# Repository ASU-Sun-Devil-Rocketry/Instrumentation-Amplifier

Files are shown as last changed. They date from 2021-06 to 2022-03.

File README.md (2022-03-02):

<h1>Rail to Rail Instrumentation Amplifier with Regulated Supply</h1>

<p><u>Current PCB Revision:</u> 2.0 <p>
<p>PCB Part Number: L0001</p>
<p>Design Folder: <a href="https://drive.google.com/drive/folders/1LhDJDFwJdzdXdzs4db-Y9qnFIhuEQvka">Click Here</a></p>

<p>The instrumentation amplifier IC uses an adjustable gain differential amplifier with buffered inputs to amplify the readings from an analog sensor using a wheatstone bridge such as a load cell or pressure transducer. The amplifier supply voltage was chosen to match that of the pressure transducers it is intended to be used with.</p>

<b>Working Directory Structure:</b>

<p>
   doc: documentation
   
   src: source design files, e.g. schematic and board files

   lib: libraries for schematic symbols and footprints

   production: files needed for pcb fabrication, e.g. gerbers, profile, drill file

   sim: simulation files 

   cad: 3d models
  
   img: images of circuit/footprints for github display 
</p>

<h2>Schematic:</h2>

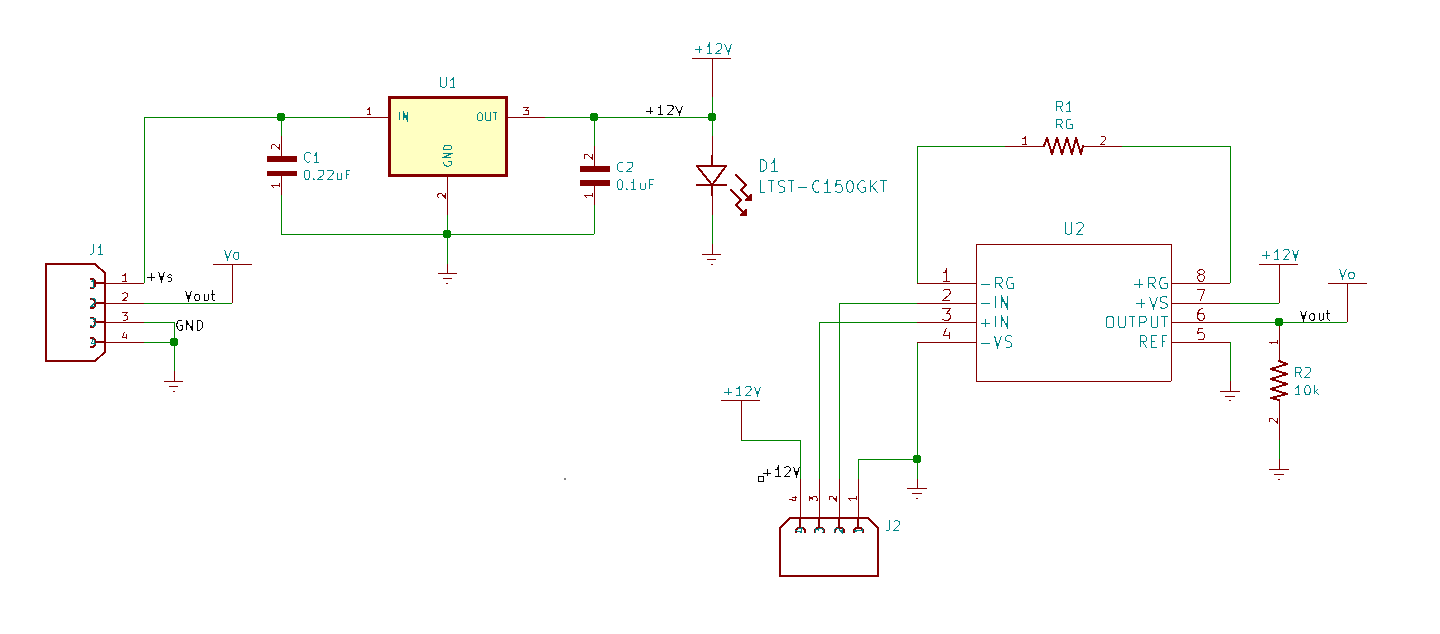
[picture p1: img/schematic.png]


<h2>PCB Layout: </h2>
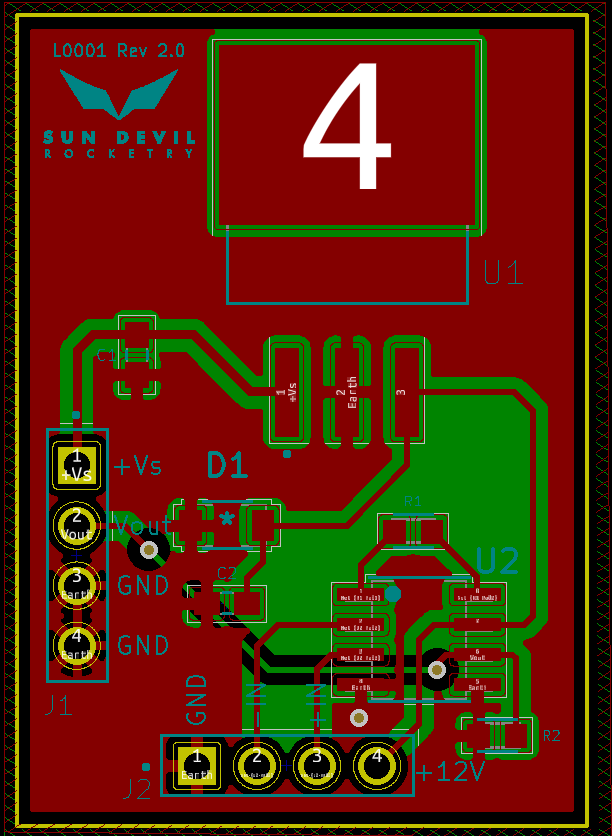
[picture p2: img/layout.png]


<h2>Gerber Veiws:</h2>
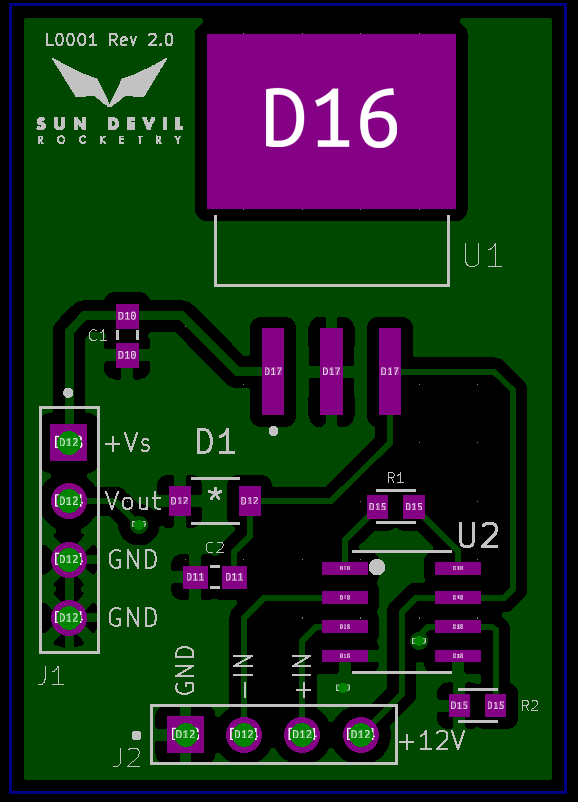
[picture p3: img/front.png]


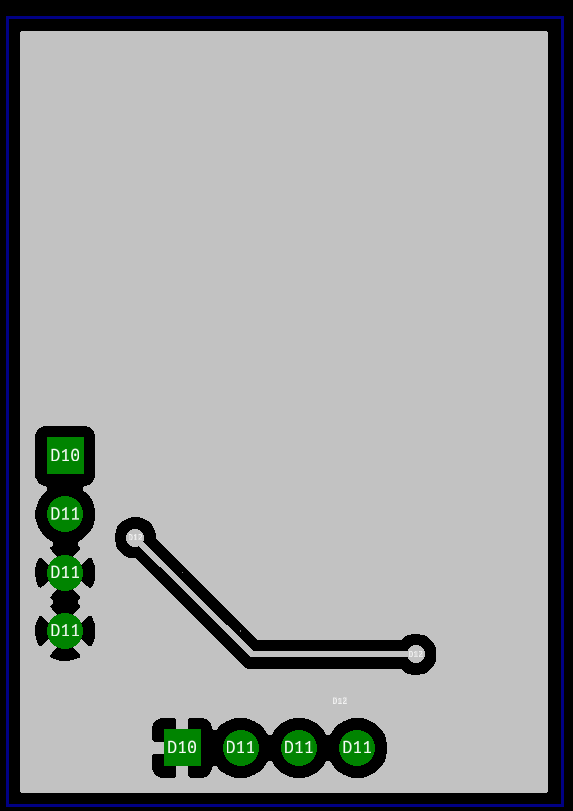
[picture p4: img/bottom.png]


<h2> 3D Model: </h2>

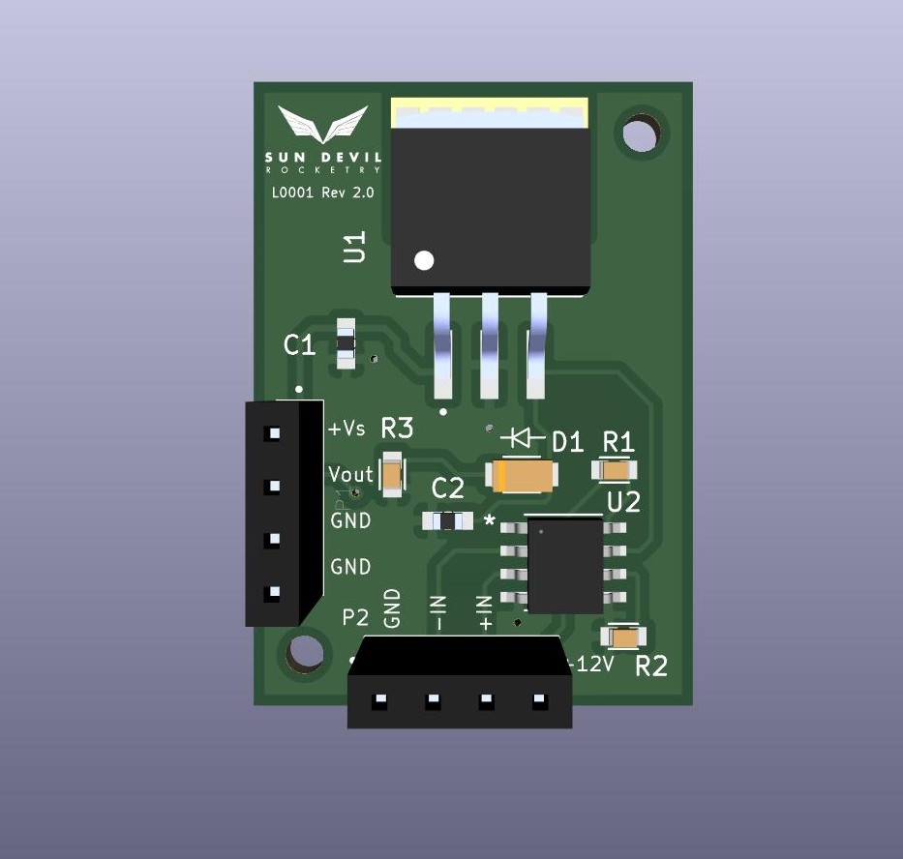
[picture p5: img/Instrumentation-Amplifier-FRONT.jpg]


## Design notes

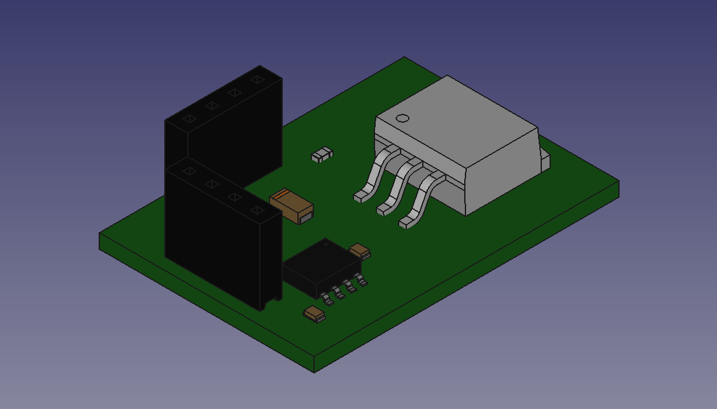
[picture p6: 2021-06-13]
img/3Dview.png

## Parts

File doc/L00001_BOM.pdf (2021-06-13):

# L0001 Instrumentation Amplifier BOM

Project: | Liquids Engine
Revision: | 2.0
Date: | 6/12/2021
Author: | Colton Acosta
Qty | Component | Manufacturer | Part Number | Designator | Do Not Populate | Price per Unit | Data Sheet | Source | Part in Stock | Alternate Parts
1 | Positive 12V linear regulator | Texas Instruments | LM7812S/NOPB | U1 | | $2.07 | AD623ARZ-R7 (https://drive.google.com/file/d/1YfVe5k8k3W6Ymcjjqmwe3NW82-qWHDOC/view?usp=sharing) | Digikey (https://www.digikey.com/en/products/detail/texas-instruments/LM7812S-NOPB/6110586) | No
1 | Rail to rail instrumentation amplifier | Analog Devices Inc. | AD623ARZ-R7 | U2 | | $5.53 | AD623ARZ-R7 (https://drive.google.com/file/d/1YfVe5k8k3W6Ymcjjqmwe3NW82-qWHDOC/view?usp=sharing) | Digikey (https://www.digikey.com/en/products/detail/analog-devices-inc/AD623ARZ-R7/652817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) | No
2 | 4 Pin connector female socket | Sullins Connector Solutions | PPTC041LFBN-RC | J1,J2 | | $0.45 | PPTC041LFBN-RC (https://drive.google.com/file/d/1xhb6gxP4Ug4C7Le1FVLg7WC_u6vesKIo/view?usp=sharing) | Digikey (https://www.digikey.com/en/products/detail/sullins-connector-solutions/PPTC041LFBN-RC/810144) | No
1 | 0.22 uF 0603 ceramic capacitor | Yageo | CC0603JRX7R8BB224 | C1 | | $0.22 | CC0603JRX7R8BB224 (https://drive.google.com/file/d/1omFNLfhEc18LIa5NOgsOFH_oAnptoYJs/view?usp=sharing) | Digikey (https://www.digikey.com/en/products/detail/yageo/CC0603JRX7R8BB224/5883662) | Yes
1 | 0.1 uF 0603 ceramic capacitor | KEMET | C0603C104J4RACTU | C2 | | $0.14 | C0603C104J4RACTU (https://drive.google.com/file/d/1a8FNZlWlnpfUzrwQWmMULMp5qRUnLx6e/view?usp=sharing) | Digikey (https://www.digikey.com/en/products/detail/kemet/C0603C104J4RACTU/411096) | Yes
1 | Green LED | Lite-On Inc | LTST-C150GKT | D1 | | $0.31 | LTST-C150GKT (https://drive.google.com/file/d/1ds0Y3mfrIqkNiykMavCPhlnYWgMl9Ngj/view?usp=sharing) | Digikey (https://www.digikey.com/en/products/detail/lite-on-inc/LTST-C150GKT/269216) | No
1 | 10kOhm 0603 resistor | Vishay | MCT0603MD1002BP100 | R2 | | $0.72 | MCT0603MD1002BP100 (https://drive.google.com/file/d/1nYTzGDgxme7YbRyGwEk438HFMVYf_WEx/view?usp=sharing) | Digikey (https://www.digikey.com/en/products/detail/vishay-beyschlag-draloric-bc-components/MCT0603MD1002BP100/2092113) | Yes
1 | 2kOhm 0603 resistor | Stackpole Electronics Inc | RNCP0603FTD2K00 | R1 | | $0.10 | RNCP0603FTD2K00 (https://drive.google.com/file/d/1EkjHNJRvKX0j5lXw98EbTa6WFv9tNLef/view?usp=sharing) | Digikey (https://www.digikey.com/en/products/detail/stackpole-electronics-inc/RNCP0603FTD2K00/2240114) | Yes

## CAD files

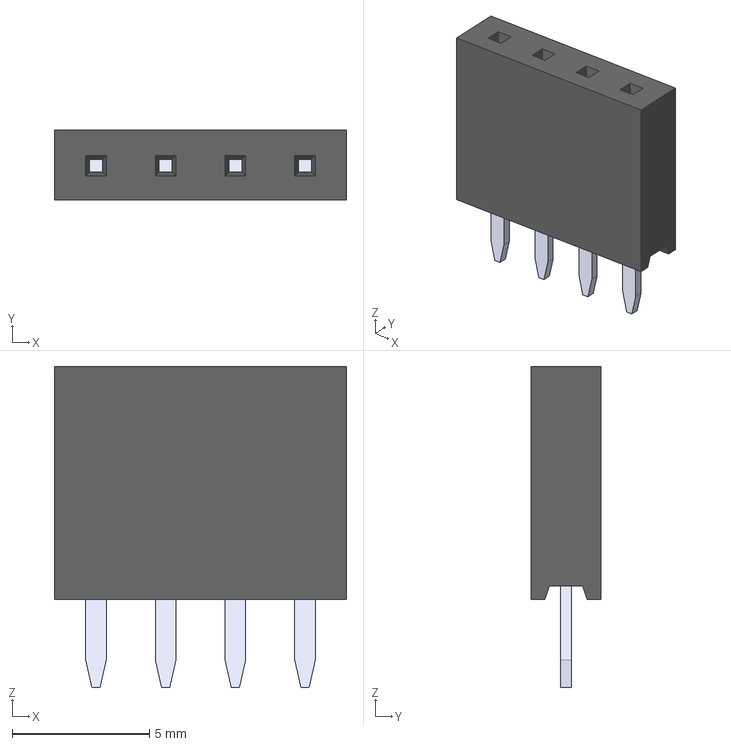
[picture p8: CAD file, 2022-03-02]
CAD/3Dfiles/Sullins_-_PPTC041LFBN-RC.step
10.7 x 2.54 x 11.7 mm

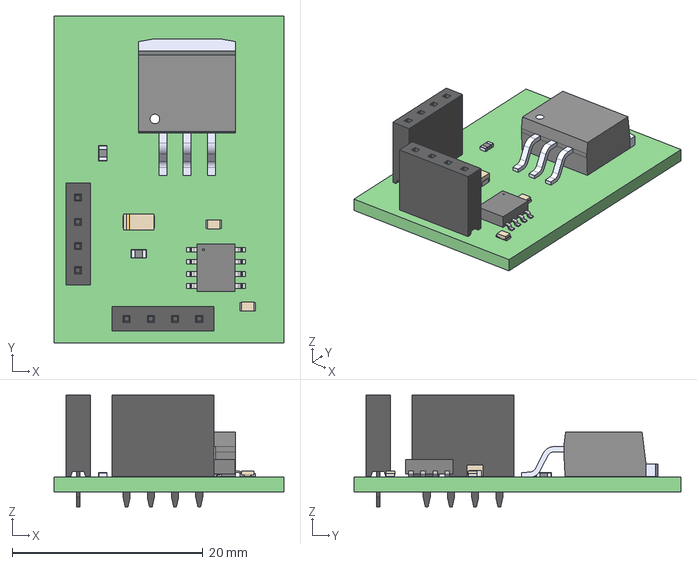
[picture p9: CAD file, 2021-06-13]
CAD/Instrumentation-Amplifier.step
24.1 x 34.3 x 11.7 mm

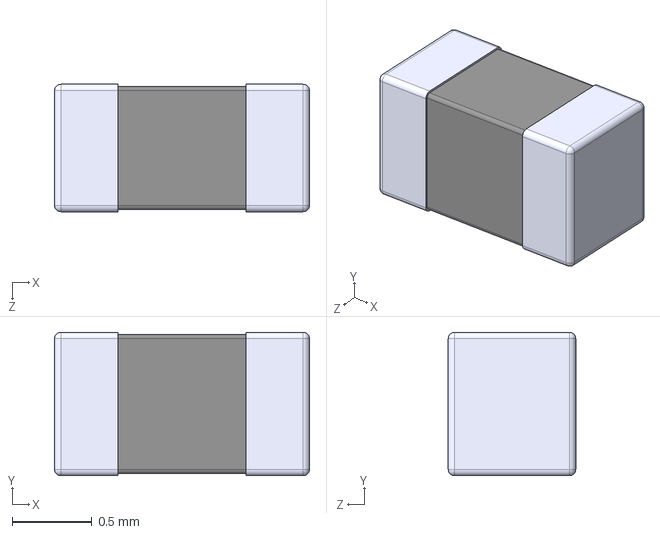
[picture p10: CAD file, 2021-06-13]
CAD/3Dfiles/CC0603JRX7R8BB224.STEP
1.60 x 0.9 x 0.8 mm

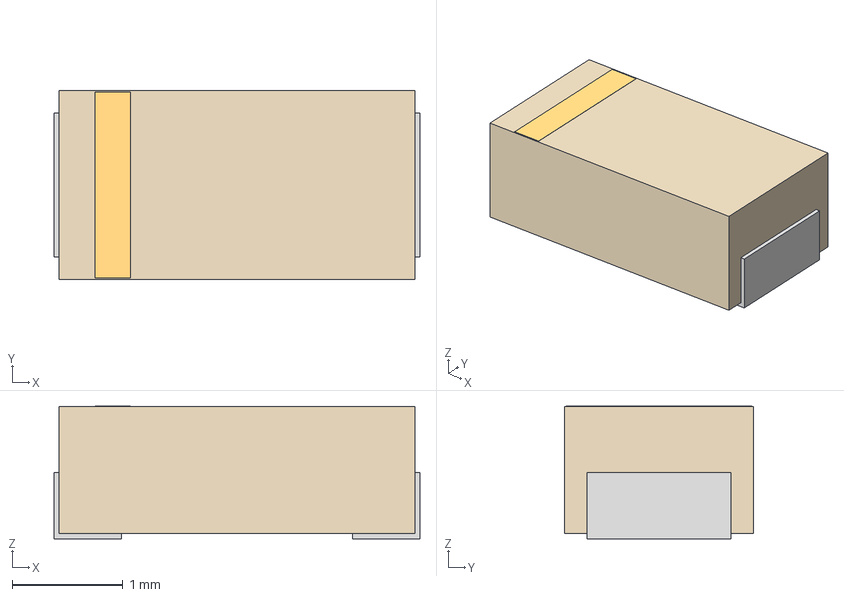
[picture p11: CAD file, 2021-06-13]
CAD/3Dfiles/LED_LTST-C150GKT_LTO.step
3.30 x 1.70 x 1.20 mm

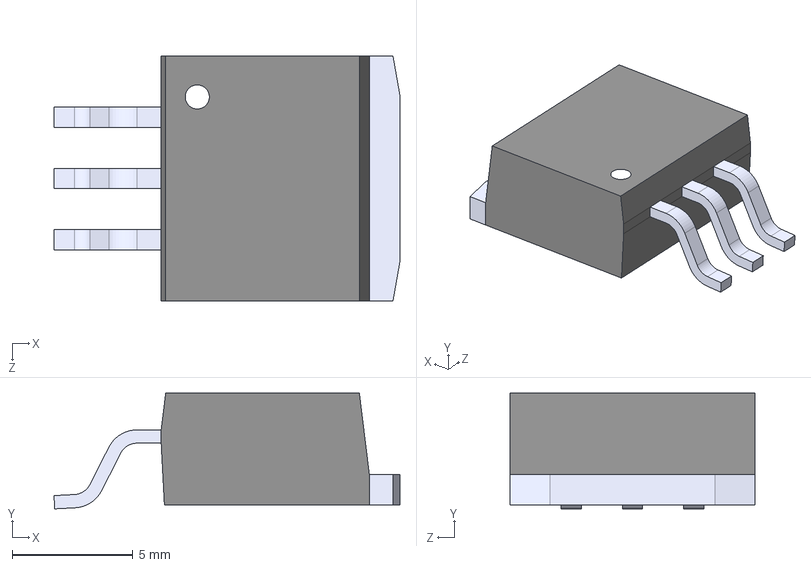
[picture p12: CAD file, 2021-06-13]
CAD/3Dfiles/NOPB.STEP
14.4 x 4.80 x 10.2 mm

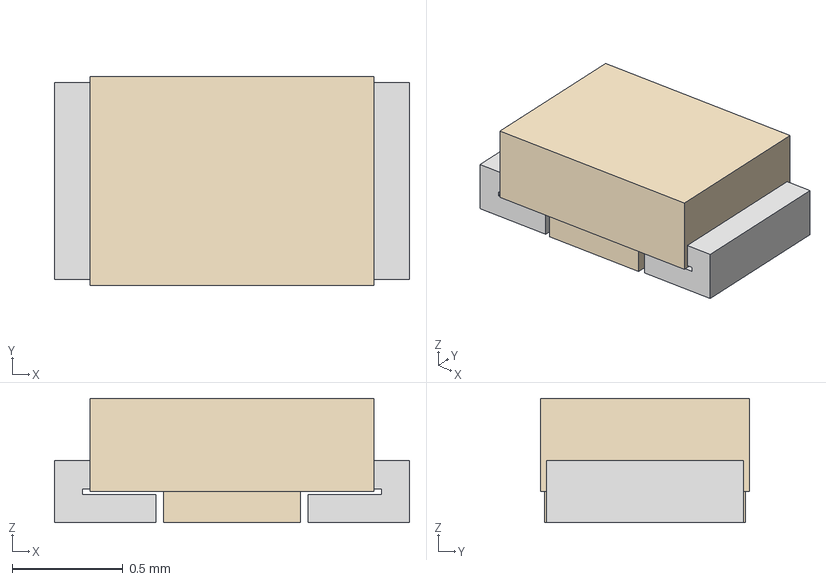
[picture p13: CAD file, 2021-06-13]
CAD/3Dfiles/RES_MCT_0603_VIS.step
1.60 x 0.94 x 0.559 mm

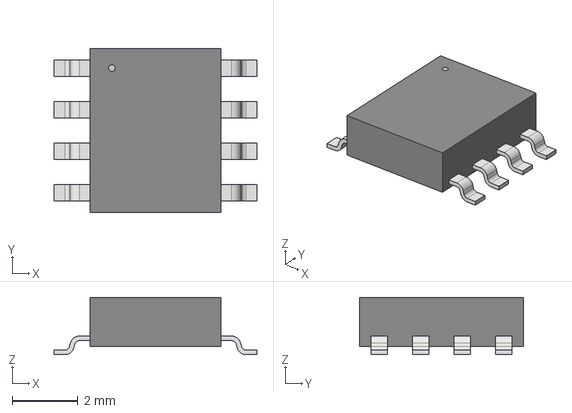
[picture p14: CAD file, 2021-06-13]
CAD/3Dfiles/R_8_ADI.step
6.20 x 5.00 x 1.75 mm

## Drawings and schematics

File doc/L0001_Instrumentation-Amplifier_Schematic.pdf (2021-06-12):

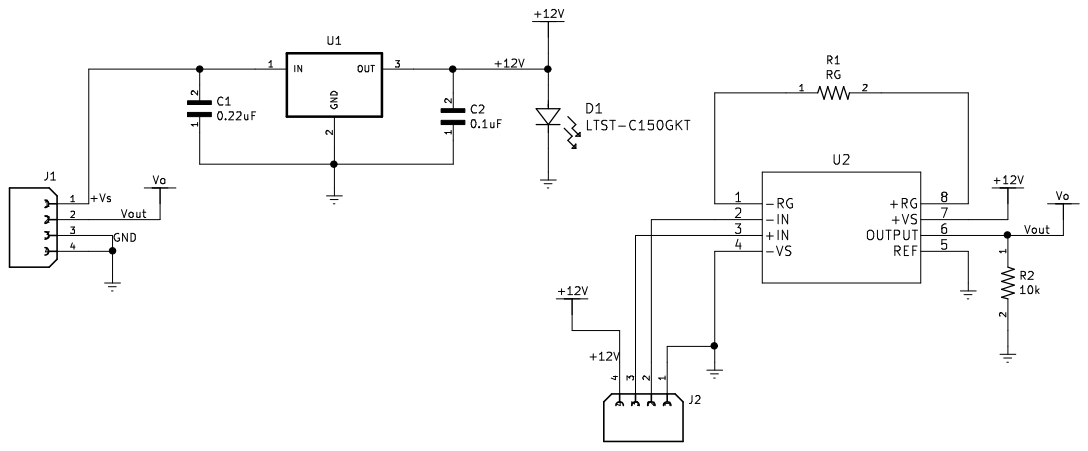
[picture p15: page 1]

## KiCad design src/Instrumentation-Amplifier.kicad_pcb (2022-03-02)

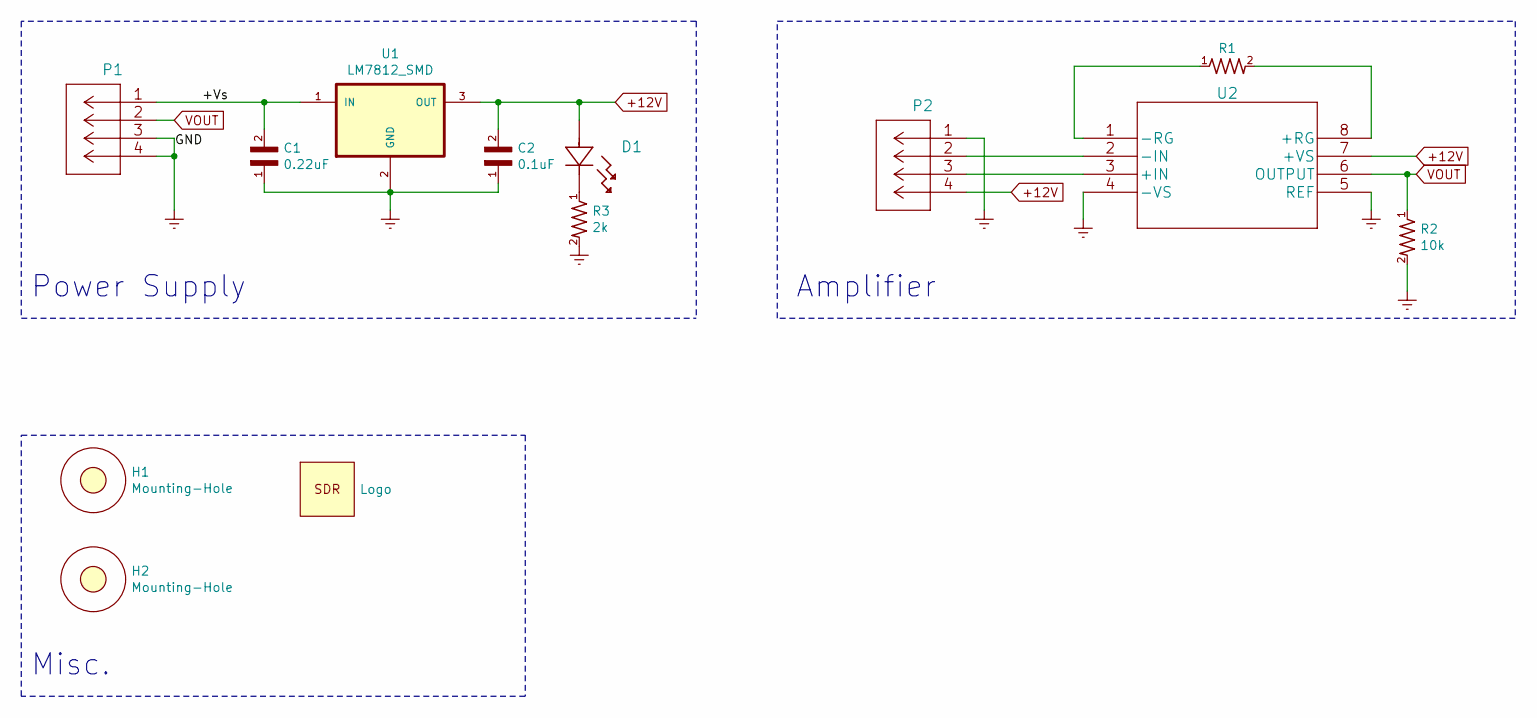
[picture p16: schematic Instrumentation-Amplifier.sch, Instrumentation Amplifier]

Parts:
C1: 0.22uF; CAP_0603
C2: 0.1uF; CAP_0603
D1: LTST-C150GKT
H1, H2: Mounting-Hole; MountingHole_2.1mm
LOGO1: Logo; logo2
P1, P2: 2043-1X04G00DAU
R1: RG; RES_0603
R2: 10k; RES_0603
R3: 2k; RES_0603
U1: LM7812_SMD; LM7812; PARTREV 34
U2: AD623ARZ-R7

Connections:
+12V: C2.2, D1.2, P2.4, U1.3 (OUT), U2.7 (+VS)
/+Vs: C1.2, P1.1, U1.1 (IN)
Earth: C1.1, C2.1, P1.3, P1.4, P2.1, R2.2, R3.2, U1.2 (GND), U2.4 (-VS), U2.5 (REF)
unnamed: D1.1, R3.1
unnamed: P2.2, U2.2 (-IN)
unnamed: P2.3, U2.3 (+IN)
unnamed: R1.1, U2.1 (-RG)
unnamed: R1.2, U2.8 (+RG)
VOUT: P1.2, R2.1, U2.6 (OUTPUT)

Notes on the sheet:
Power Supply
Amplifier
Misc.

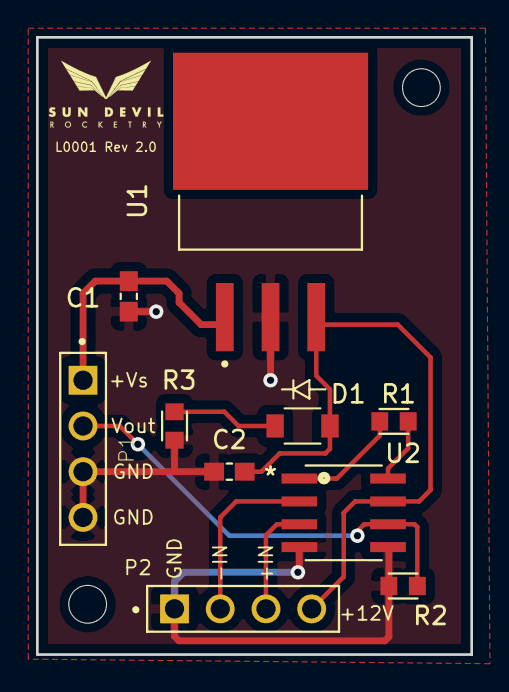
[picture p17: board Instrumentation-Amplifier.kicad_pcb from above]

Board: 2 copper layers, 24.1 x 34.3 mm, 13 parts (0 on the bottom side), 9 nets.

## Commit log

2021-06-05 Copied files from old repo
    [InstrumentationAmplifier.brd, InstrumentationAmplifier.sch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]
2021-06-05 Updated PCB Revision Number
2021-06-12 Revision 2 uploaded
    [Instrumentation-Amplifier.kicad_pcb, Instrumentation-Amplifier.sch, InstrumentationAmplifier.brd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]
2021-06-13 Created first revision of rev 2 BOM
    [R_8_ADI.step]
2021-06-13 Added 3d files for parts on BOM
    [CC0603JRX7R8BB224.STEP, LED_LTST-C150GKT_LTO.step, NOPB.STEP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]
2021-06-13 Updated CAD folder README description
2021-06-13 Generated Rev 2.0 Gerbers
    [Instrumentation-Amplifier-B_Cu.gbr, Instrumentation-Amplifier-B_Mask.gbr, Instrumentation-Amplifier-B_Paste.gbr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]
2021-06-13 Added gerberView images
2021-06-13 Generated Step file
    [Instrumentation-Amplifier.step]
2021-06-13 Cleaned up file structure
    [Instrumentation-Amplifier.kicad_pcb]
2021-06-20 Started method for resistor calculations
2021-06-20 Added function for calculating gain resistor
2021-06-26 Modified 3D cap fit on footprint
2021-06-30 Re-added power library
    [Instrumentation-Amplifier.sch]
2021-09-28 Added earth symbol to component lib
    [Instrumentation-Amplifier.sch]
2021-09-28 Swapped 4 pin header component symbol
    [Instrumentation-Amplifier.sch]
2021-09-28 Updated schematic with global labels
    [Instrumentation-Amplifier.sch]
2021-09-28 Updated PCB with new connectors
    [Instrumentation-Amplifier.kicad_pcb, Instrumentation-Amplifier.sch]
2021-09-28 Added mounting holes
    [Instrumentation-Amplifier.kicad_pcb, Instrumentation-Amplifier.sch]
2021-10-02 Added LED resistor
    [Instrumentation-Amplifier.sch]
2022-03-02 Added new 3D view image
    [Instrumentation-Amplifier-B_Cu.gbr, Instrumentation-Amplifier-B_Mask.gbr, Instrumentation-Amplifier-B_Paste.gbr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]

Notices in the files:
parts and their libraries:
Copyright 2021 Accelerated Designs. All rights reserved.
